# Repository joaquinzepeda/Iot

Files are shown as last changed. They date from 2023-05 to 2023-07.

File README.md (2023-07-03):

# Iot
Repositorio códigos curso Análisis y Diseño de Sistemas basados en Internet de las Cosas (IoT).

## Integrantes 
Ricardo Garcia, FCFM.  
Benjamín Irarrazabal, FCFM.  
Joaquín Zepeda, FCFM.  

# Diseño PCB

Se diseño la siguiente placa PCB para un sistema de regadio automático. 
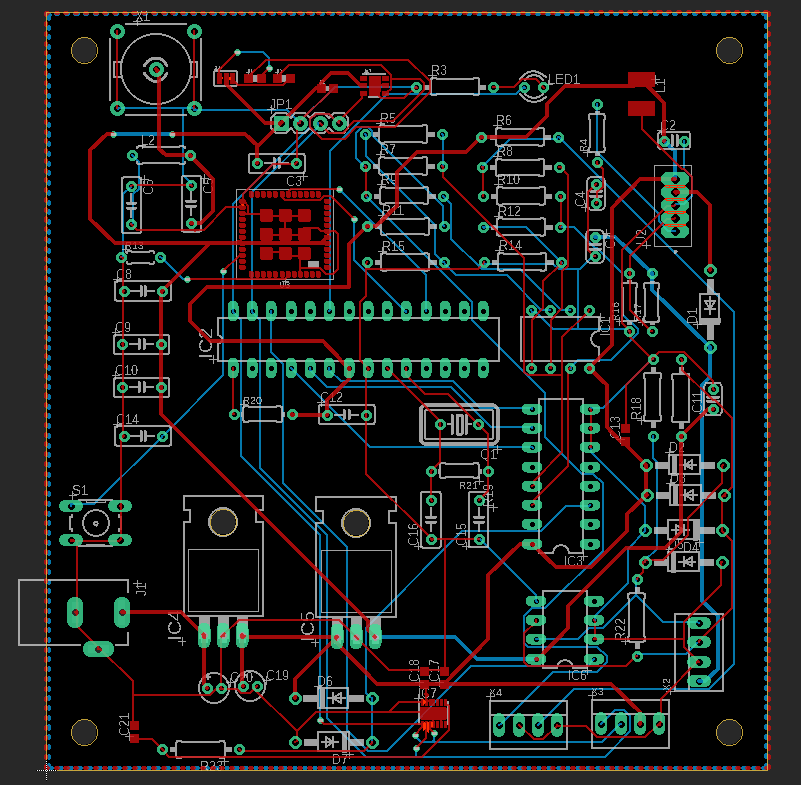
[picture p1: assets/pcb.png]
pcb


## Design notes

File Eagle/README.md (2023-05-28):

# Iot
Repositorio códigos curso Análisis y Diseño de Sistemas basados en Internet de las Cosas (IoT).

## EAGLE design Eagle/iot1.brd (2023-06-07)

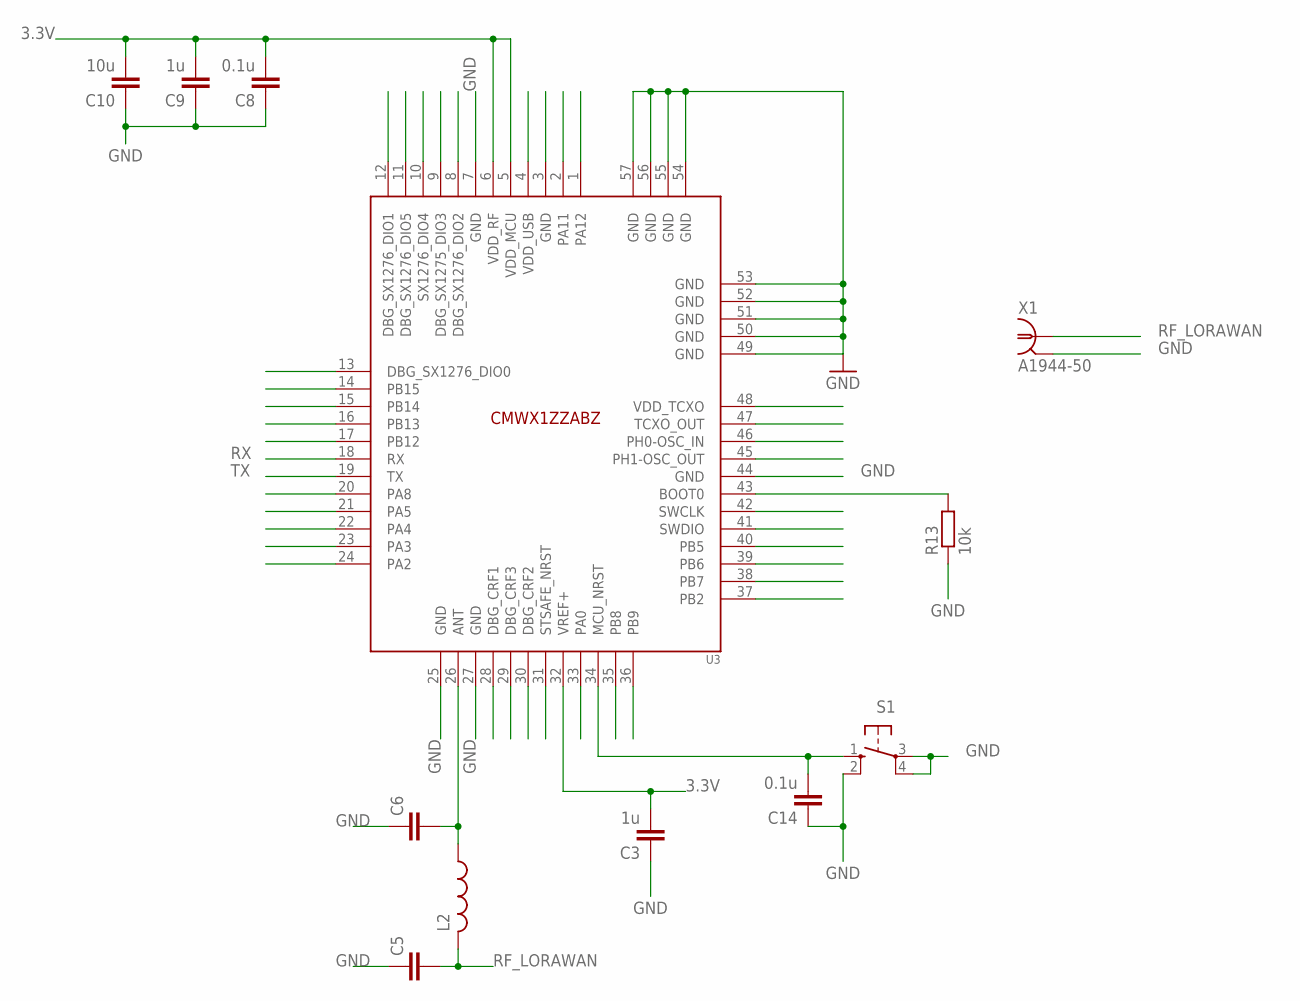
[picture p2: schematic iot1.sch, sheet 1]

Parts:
C3, C9: 1u; C050-025X075
C5, C6: C-EU050-025X075; C050-025X075
C8, C14: 0.1u; C050-025X075
C10: 10u; C050-025X075
L2: L-US0207/7; 0207/7
R13: 10k; 0204/5
S1: 10-XX; B3F-10XX
U3: CMWX1ZZABZ
X1: A1944-50; A1944

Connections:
3.3V: C3.2, C8.2, C9.2, C10.2, U3.5 (VDD_MCU), U3.6 (VDD_RF), U3.32 (VREF+); also elsewhere on the board
GND: C3.1, C5.1, C6.1, C8.1, C9.1, C10.1, C14.1, R13.1, S1.2 (S1), S1.3, S1.4 (P1), U3.7 (GND), U3.25 (GND), U3.27 (GND), U3.44 (GND), U3.49 (GND), U3.50 (GND), U3.51 (GND), U3.52 (GND), U3.53 (GND), U3.54 (GND), U3.55 (GND), U3.56 (GND), U3.57 (GND), X1.2, X1.3 (2), X1.4 (2), X1.5 (2); also elsewhere on the board
unnamed: C6.2, L2.1, U3.26 (ANT)
unnamed: C14.2, S1.1 (S), U3.34 (MCU_NRST)
unnamed: R13.2, U3.43 (BOOT0)
RF_LORAWAN: C5.2, L2.2, X1.1
RX: U3.18 (RX); also elsewhere on the board
TX: U3.19 (TX); also elsewhere on the board

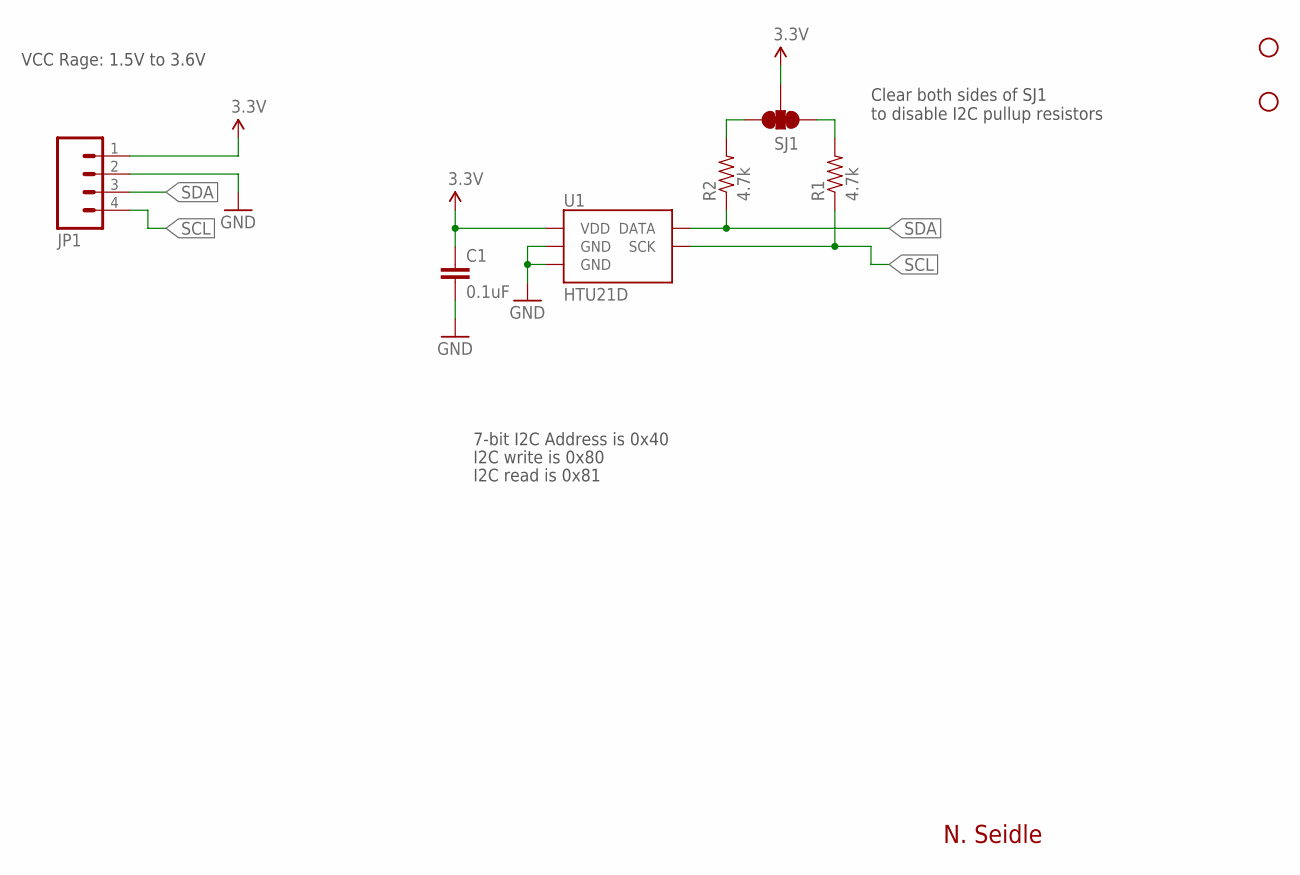
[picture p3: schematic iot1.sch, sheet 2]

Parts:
C1: 0.1uF; 0603-CAP
JP1: M04PTH; 1X04
R1, R2: 4.7k; 0603-RES
SJ1: SOLDERJUMPER_2WAYPASTE1&2&3; SJ_3_PASTE1&2&3
STANDOFF1, STANDOFF3: STAND-OFF
U1: HTU21D

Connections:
3.3V: C1.1, JP1.1, SJ1.2, U1.VDD; also elsewhere on the board
GND: C1.2, JP1.2, U1.7 (GND), U1.GND; also elsewhere on the board
unnamed: R2.2, SJ1.3
unnamed: R1.2, SJ1.1
SCL: JP1.4, R1.1, U1.SCK; also elsewhere on the board
SDA: JP1.3, R2.1, U1.DATA; also elsewhere on the board

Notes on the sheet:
N. Seidle
Clear both sides of SJ1 to disable I2C pullup resistors
VCC Rage: 1.5V to 3.6V
7-bit I2C Address is 0x40
I2C write is 0x80
I2C read is 0x81

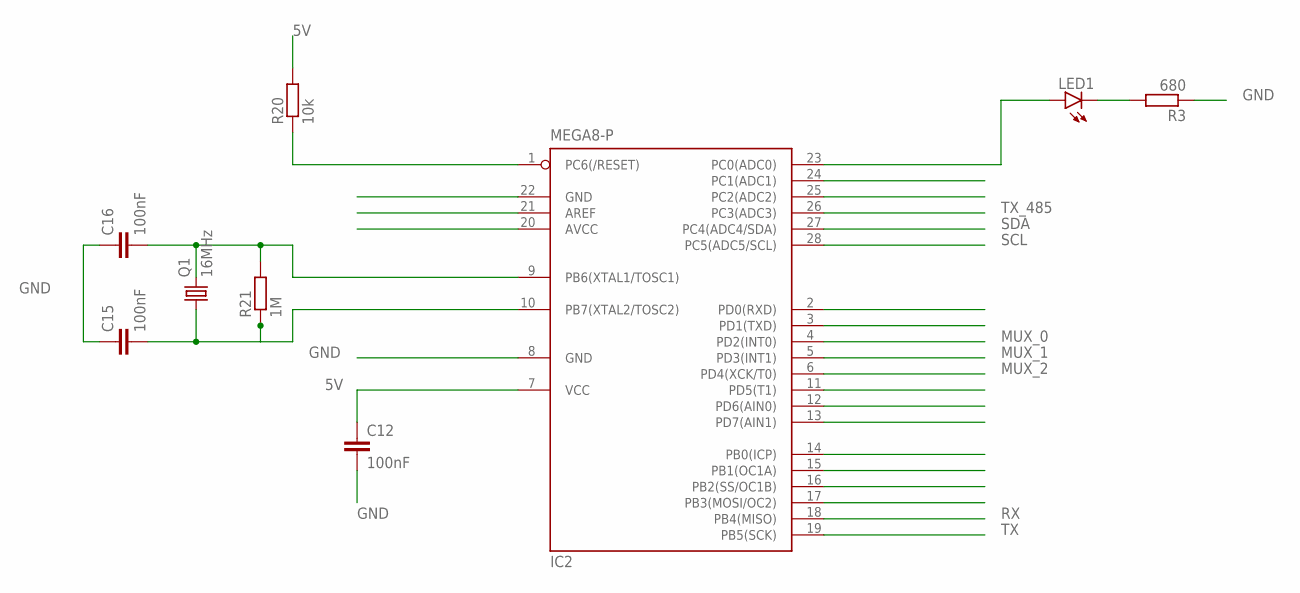
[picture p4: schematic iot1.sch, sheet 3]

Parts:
C12, C15, C16: 100nF; C050-025X075
IC2: MEGA8-P; DIL28-3
LED1: LED3MM
Q1: 16MHz; HC18U-V
R3: 680; 0207/10
R20: 10k; 0204/7
R21: 1M; 0204/7

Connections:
5V: C12.1, IC2.7 (VCC), R20.2; also elsewhere on the board
GND: C12.2, C15.1, C16.1, IC2.8 (GND), R3.1; also elsewhere on the board
MUX_0: IC2.4 (PD2(INT0)); also elsewhere on the board
MUX_1: IC2.5 (PD3(INT1)); also elsewhere on the board
MUX_2: IC2.6 (PD4(XCK/T0)); also elsewhere on the board
unnamed: IC2.23 (PC0(ADC0)), LED1.A
unnamed: IC2.1 (PC6(/RESET)), R20.1
unnamed: C15.2, IC2.10 (PB7(XTAL2/TOSC2)), Q1.1, R21.1
unnamed: C16.2, IC2.9 (PB6(XTAL1/TOSC1)), Q1.2, R21.2
unnamed: LED1.K (C), R3.2
RX: IC2.18 (PB4(MISO)); also elsewhere on the board
SCL: IC2.28 (PC5(ADC5/SCL)); also elsewhere on the board
SDA: IC2.27 (PC4(ADC4/SDA)); also elsewhere on the board
TX: IC2.19 (PB5(SCK)); also elsewhere on the board
TX_485: IC2.26 (PC3(ADC3)); also elsewhere on the board

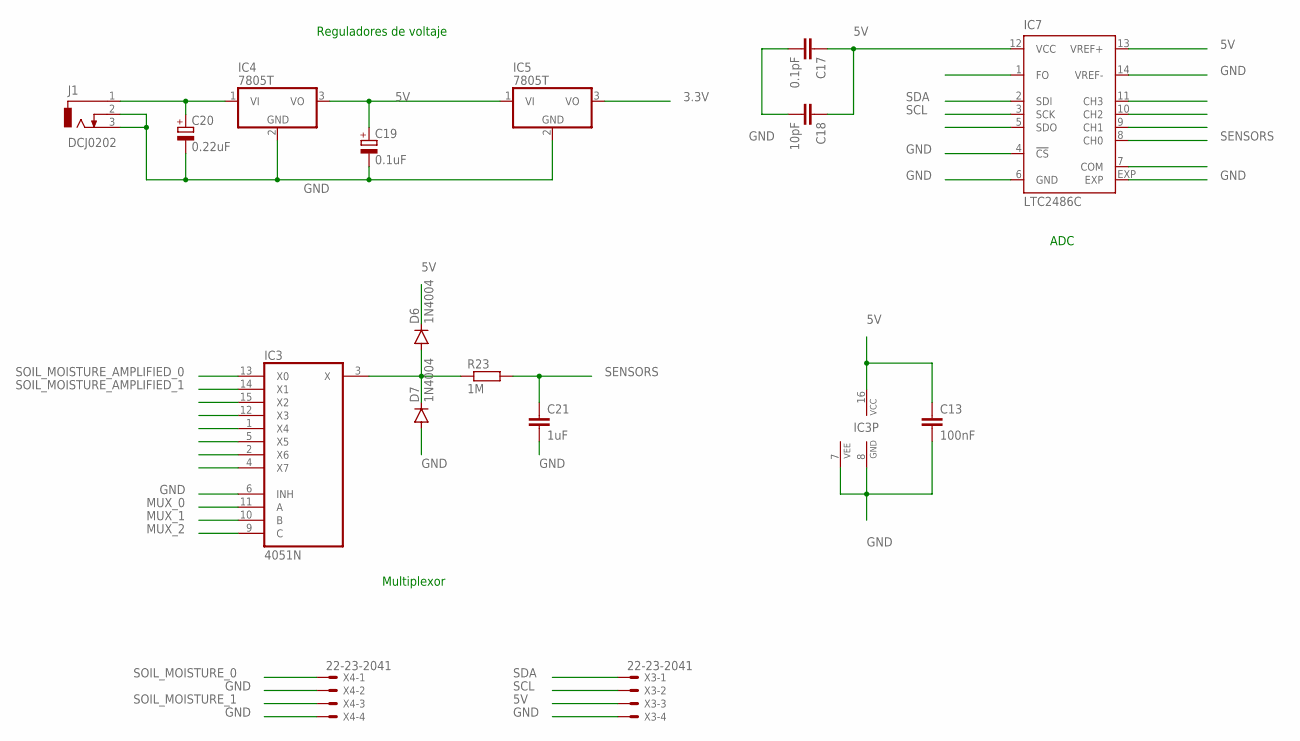
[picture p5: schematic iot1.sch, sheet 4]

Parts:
C13: 100nF; C0603
C17: 0.1pF; C0603
C18: 10pF; C0603
C19: 0.1uF; E1,8-4
C20: 0.22uF; E1,8-4
C21: 1uF; C0603
D6, D7: 1N4004; DO41-10
IC3: 4051N; DIL16
IC4, IC5: 7805T; TO220H
IC7: LTC2486C; DFN14-4X3
J1: DCJ0202
R23: 1M; 0207/10
X3, X4: 22-23-2041

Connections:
3.3V: IC5.3 (VO); also elsewhere on the board
5V: C13.1, C17.1, C18.1, C19.+, D6.C, IC3.16 (VCC), IC4.3 (VO), IC5.1 (VI), IC7.12 (VCC), IC7.13 (VREF+), X3.3; also elsewhere on the board
GND: C13.2, C17.2, C18.2, C19.-, C20.-, C21.2, D7.A, IC3.6 (INH), IC3.7 (VEE), IC3.8 (GND), IC4.2 (GND), IC5.2 (GND), IC7.4 (!CS), IC7.6 (GND), IC7.14 (VREF-), IC7.EXP, J1.2, J1.3, X3.4, X4.2, X4.4; also elsewhere on the board
MUX_0: IC3.11 (A); also elsewhere on the board
MUX_1: IC3.10 (B); also elsewhere on the board
MUX_2: IC3.9 (C); also elsewhere on the board
S: D6.A, D7.C, IC3.3 (X), R23.1
SCL: IC7.1 (FO), IC7.3 (SCK), X3.2; also elsewhere on the board
SDA: IC7.2 (SDI), X3.1; also elsewhere on the board
SENSORS: C21.1, IC7.8 (CH0), R23.2
SOIL_MOISTURE_0: X4.1; also elsewhere on the board
SOIL_MOISTURE_1: X4.3; also elsewhere on the board
SOIL_MOISTURE_AMPLIFIED_0: IC3.13 (X0); also elsewhere on the board
SOIL_MOISTURE_AMPLIFIED_1: IC3.14 (X1); also elsewhere on the board
V_IN: C20.+, IC4.1 (VI), J1.1

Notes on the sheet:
Multiplexor
ADC
Reguladores de voltaje

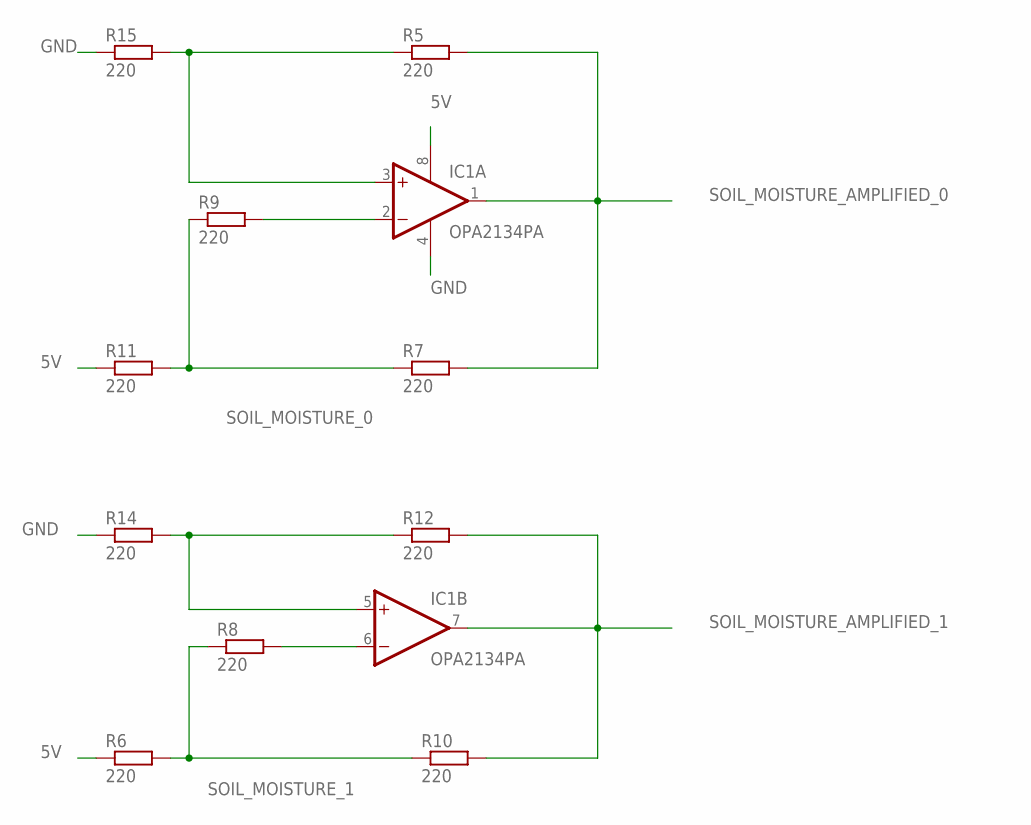
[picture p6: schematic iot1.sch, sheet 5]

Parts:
IC1: OPA2134PA; DIL08
R5, R6, R7, R8, R9, R10, R11, R12, R14, R15: 220; 0207/10

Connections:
5V: IC1.8 (V+), R6.1, R11.1; also elsewhere on the board
GND: IC1.4 (V-), R14.1, R15.1; also elsewhere on the board
unnamed: IC1.3 (+IN), R5.1, R15.2
unnamed: IC1.2 (-IN), R9.2
unnamed: IC1.5 (+IN), R12.1, R14.2
unnamed: IC1.6 (-IN), R8.2
SOIL_MOISTURE_0: R7.1, R9.1, R11.2; also elsewhere on the board
SOIL_MOISTURE_1: R6.2, R8.1, R10.1; also elsewhere on the board
SOIL_MOISTURE_AMPLIFIED_0: IC1.1 (OUT), R5.2, R7.2; also elsewhere on the board
SOIL_MOISTURE_AMPLIFIED_1: IC1.7 (OUT), R10.2, R12.2; also elsewhere on the board

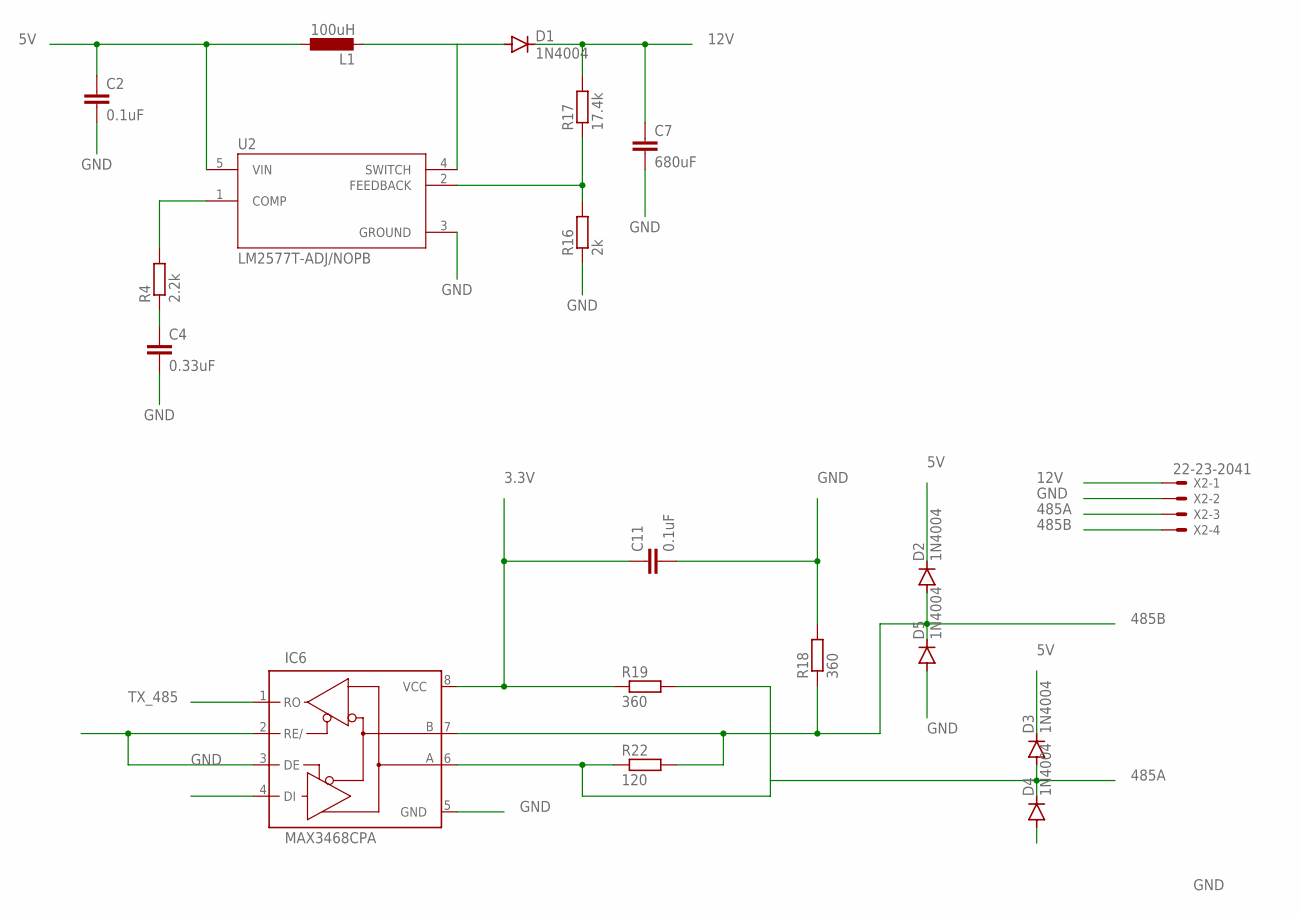
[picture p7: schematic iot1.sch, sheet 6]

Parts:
C2, C11: 0.1uF; C025-024X044
C4: 0.33uF; C025-024X044
C7: 680uF; C025-024X044
D1, D2, D3, D4, D5: 1N4004; DO41-10
IC6: MAX3468CPA; DIL08
L1: 100uH; L1812
R4: 2.2k; 0204/7
R16: 2k; 0204/7
R17: 17.4k; 0204/7
R18, R19: 360; 0207/10
R22: 120; 0207/10
U2: LM2577T-ADJ/NOPB; VREG_LM2577T-ADJ/NOPB
X2: 22-23-2041

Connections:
3.3V: C11.1, IC6.8 (VCC), R19.1; also elsewhere on the board
5V: C2.1, D2.C, D3.C, L1.1, U2.5 (VIN); also elsewhere on the board
12V: C7.1, D1.C, R17.2, X2.1
485A: D3.A, D4.C, IC6.6 (A), R19.2, R22.1, X2.3
485B: D2.A, D5.C, IC6.7 (B), R18.1, R22.2, X2.4
GND: C2.2, C4.2, C7.2, C11.2, D4.A, D5.A, IC6.2 (RE/), IC6.3 (DE), IC6.5 (GND), R16.1, R18.2, U2.3 (GROUND), X2.2; also elsewhere on the board
unnamed: D1.A, L1.2, U2.4 (SWITCH)
unnamed: R4.2, U2.1 (COMP)
unnamed: C4.1, R4.1
unnamed: R16.2, R17.1, U2.2 (FEEDBACK)
TX_485: IC6.1 (RO); also elsewhere on the board

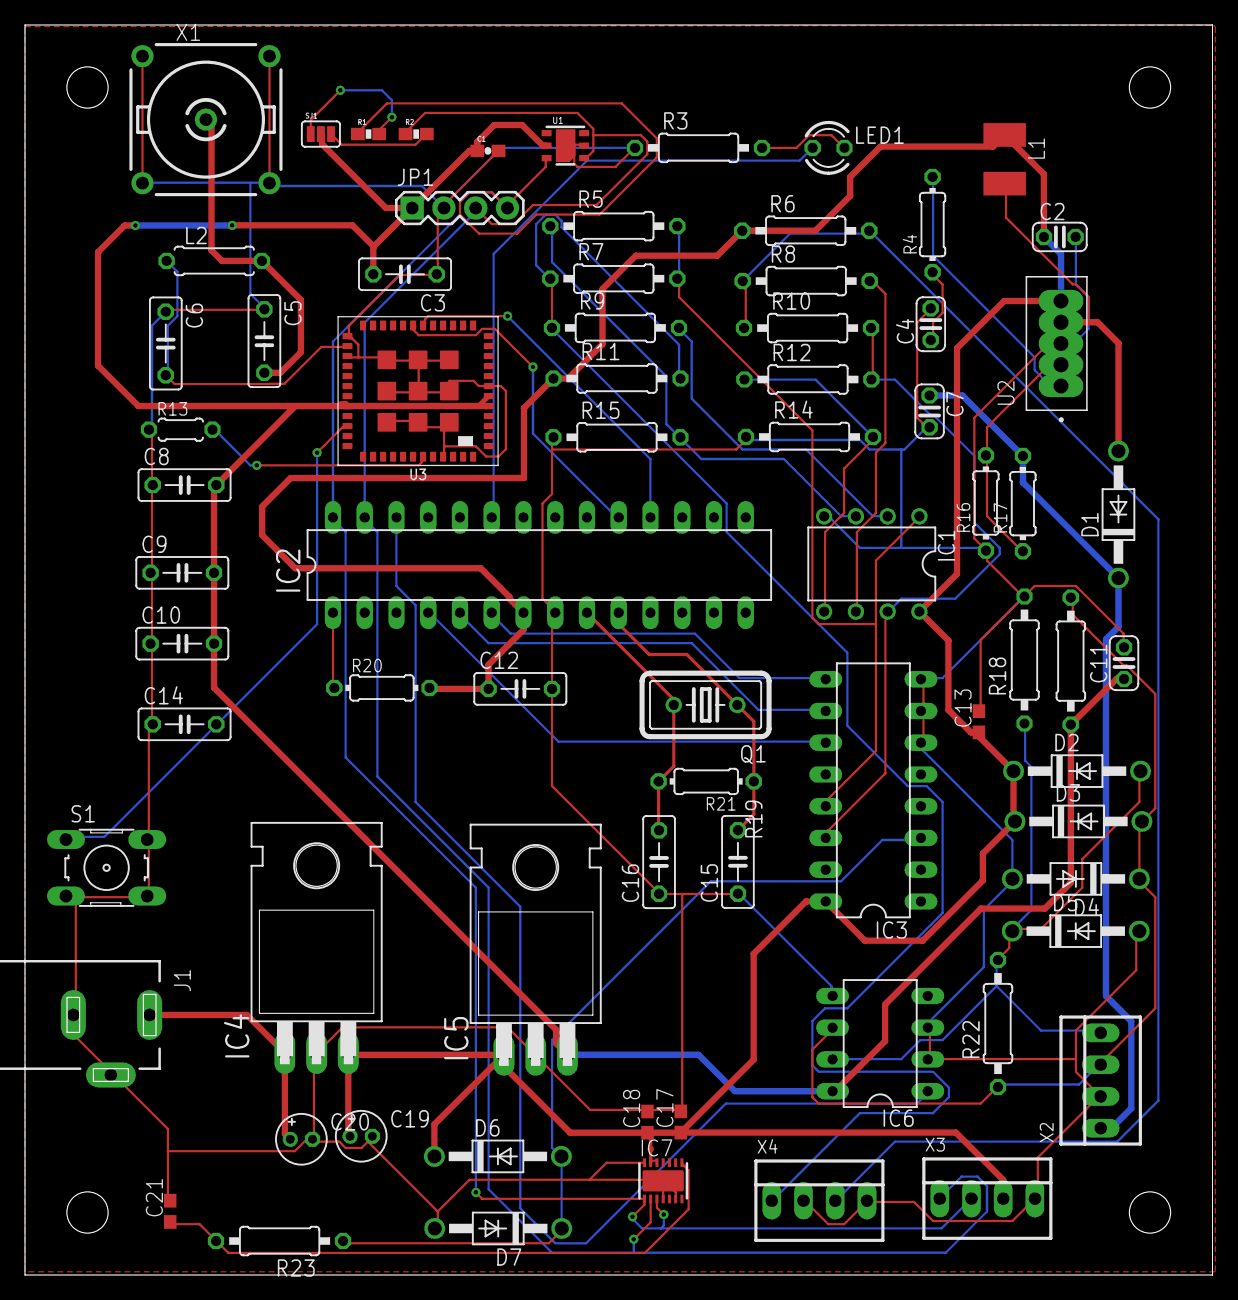
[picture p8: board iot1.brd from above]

Board: 2 copper layers, 95.0 x 100.0 mm, 77 parts (0 on the bottom side), 40 nets.

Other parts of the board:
STANDOFF2, STANDOFF4: STAND-OFF

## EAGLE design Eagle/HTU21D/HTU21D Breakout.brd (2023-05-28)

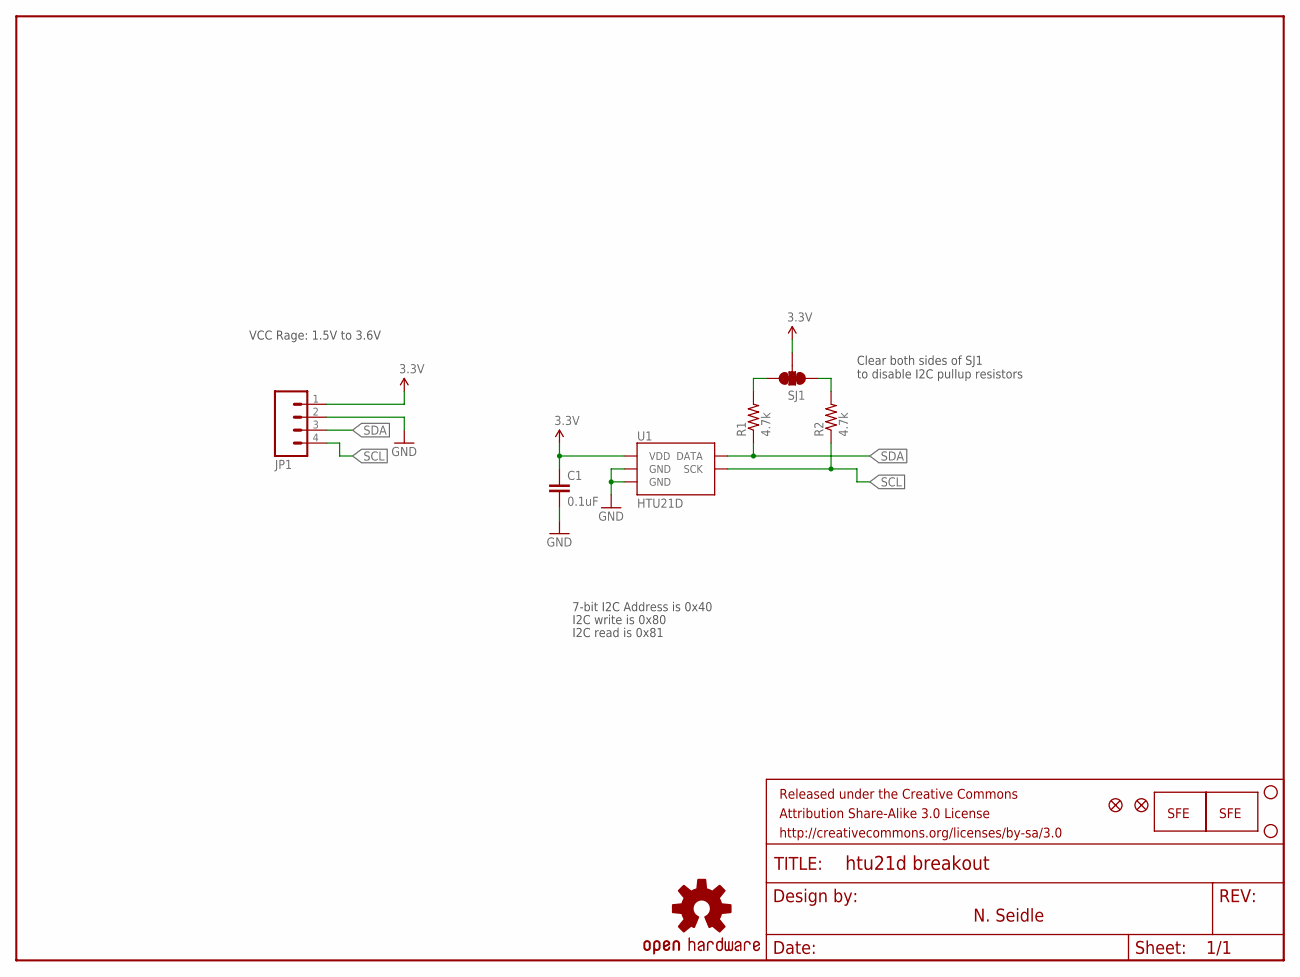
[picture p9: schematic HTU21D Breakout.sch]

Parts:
C1: 0.1uF; 0603-CAP
FRAME2: FRAME-LETTER; CREATIVE_COMMONS
JP1: M04PTH; 1X04
JP2: LOGO-SFENW2; SFE-NEW-WEB
JP3, JP4: FIDUCIALUFIDUCIAL; MICRO-FIDUCIAL
LOGO1: LOGO-SFESK; SFE-LOGO-FLAME
LOGO2: OSHW-LOGOS; OSHW-LOGO-S
R1, R2: 4.7k; 0603-RES
SJ1: SOLDERJUMPER_2WAYPASTE1&2&3; SJ_3_PASTE1&2&3
STANDOFF1, STANDOFF2: STAND-OFF
U1: HTU21D

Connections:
3.3V: C1.1, JP1.1, SJ1.2, U1.VDD
GND: C1.2, JP1.2, U1.7 (GND), U1.GND
unnamed: R1.2, SJ1.3
unnamed: R2.2, SJ1.1
SCL: JP1.4, R2.1, U1.SCK
SDA: JP1.3, R1.1, U1.DATA

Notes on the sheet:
N. Seidle
Clear both sides of SJ1 to disable I2C pullup resistors
VCC Rage: 1.5V to 3.6V
7-bit I2C Address is 0x40
I2C write is 0x80
I2C read is 0x81

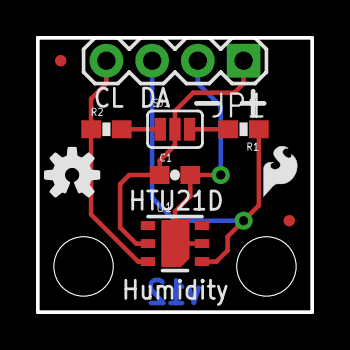
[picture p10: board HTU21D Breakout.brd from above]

Board: 2 copper layers, 15.2 x 15.2 mm, 14 parts (1 on the bottom side), 6 nets.

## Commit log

2023-05-28 esquematicos base
    [HTU21D Breakout.brd, HTU21D Breakout.sch, iot1.brd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]
2023-05-31 adding MEGA8-P controller
    [iot1.brd, iot1.sch]
2023-06-01 adding moisture input and adding voltage regulator
    [iot1.brd, iot1.sch]
2023-06-01 adding power supply
    [iot1.brd, iot1.sch]
2023-06-01 antena, power supply y conexiones lorawan
    [iot1.brd, iot1.sch]
2023-06-03 3.3V regulator, multiplexer
    [iot1.brd, iot1.sch]
2023-06-03 1Hz filter
    [iot1.brd, iot1.sch]
2023-06-03 4-20ma amplification for soil moisture sensors
    [iot1.brd, iot1.sch]
2023-06-03 rearranging items
    [iot1.brd, iot1.sch]
2023-06-06 adding MAX485 module
    [iot1.brd, iot1.sch]
2023-06-06 Step-up 5 to 12V
    [iot1.brd, iot1.sch]
2023-06-06 Entrada Sensor de Temperatura y Humedad Ambiente
    [iot1.brd, iot1.sch]
2023-06-06 adding MAX3468
    [iot1.brd, iot1.sch, rs485.sch]
2023-06-07 adding important wires
    [iot1.brd]
2023-06-07 all conections
    [iot1.brd]
2023-06-07 renumbering board components
    [iot1.brd, iot1.sch]
2023-06-07 adding component's values
    [iot1.brd, iot1.sch]
2023-06-07 fixing wiring errors
    [iot1.brd]
2023-06-07 adding gnds planes
    [iot1.brd]
2023-07-03 reorganizing folders
    [HTU21D Breakout.brd, HTU21D Breakout.sch, iot1.brd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]
2023-07-03 imagenes pcb

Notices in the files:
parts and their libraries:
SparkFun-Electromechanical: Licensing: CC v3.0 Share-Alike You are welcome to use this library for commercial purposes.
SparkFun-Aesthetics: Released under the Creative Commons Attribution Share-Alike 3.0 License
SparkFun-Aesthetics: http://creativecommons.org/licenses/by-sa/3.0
